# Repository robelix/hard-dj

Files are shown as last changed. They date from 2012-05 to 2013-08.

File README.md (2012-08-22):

# HardDJ - Arduino Mega based DJ MIDI Controller

using old Harddisks as jog wheels

Have a look to the wiki https://github.com/robelix/hard-dj/wiki for more documentation  

## Contents:

* arduino/libraries - Required arduino libs
* arduino/sketchbook - arduino code
* encoder - encoder wheels for lasercutting
* mixxx - MIDI-mapping for mixxx http://mixxx.org/
* eagle - sketches and pcbs
* ttymidi - serial to midi tool for linux

## License:
CC-BY-SA Roland "robelix" Obermayer <roland at robelix.com>
http://creativecommons.org/licenses/by-sa/3.0/at/

## Tools and libs with diffrent licenses

### Encoder wheel generator script
encoder/make_encoder.perl  
http://thedenneys.org/pub/robot/encoders/  
by Bryce Denney <bryce at tlw.com>  
License: GPL 2 or later  

### Arduino MIDI lib
arduino/libraries/MIDI/  
http://arduino.cc/playground/Main/MIDILibrary  
by Francois Best  
License: GPL  

### Arduino Encoder lib
arduino/libraries/Encoder/  
http://www.pjrc.com/teensy/td_libs_Encoder.html  
by PJRC.COM, LLC - Paul Stoffregen <paul@pjrc.com>  
License: MIT  

### ttymidi
ttymidi/  
http://www.varal.org/ttymidi/  
by Thiago Teixeira, Jari Suominen  
License GPL 3 or later

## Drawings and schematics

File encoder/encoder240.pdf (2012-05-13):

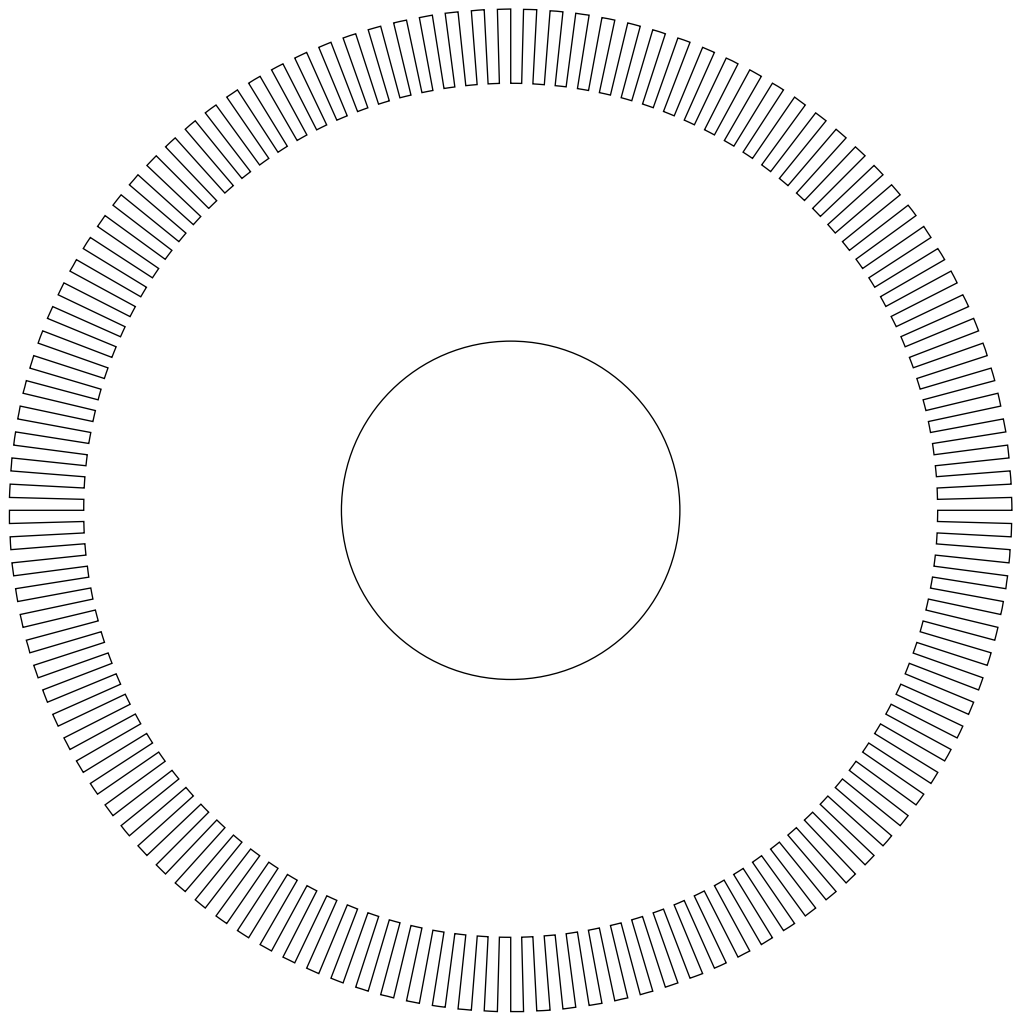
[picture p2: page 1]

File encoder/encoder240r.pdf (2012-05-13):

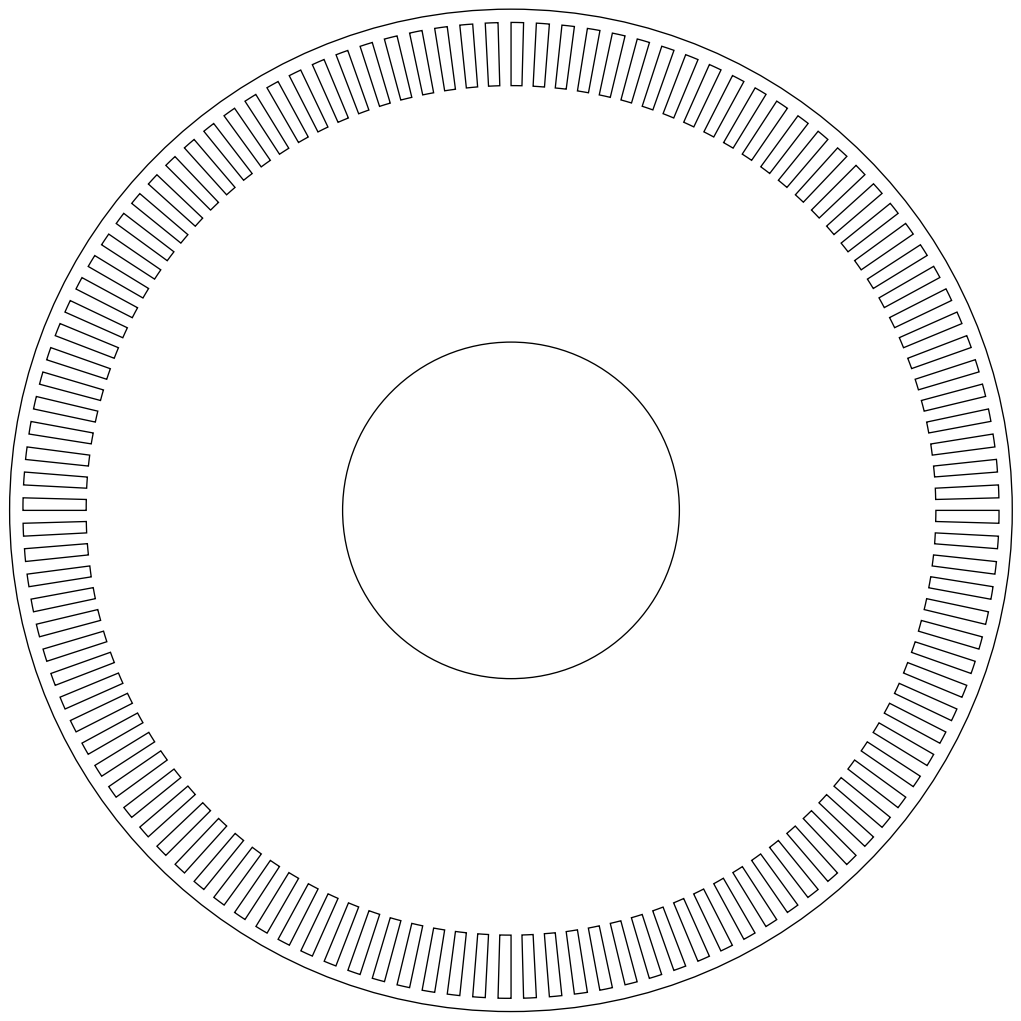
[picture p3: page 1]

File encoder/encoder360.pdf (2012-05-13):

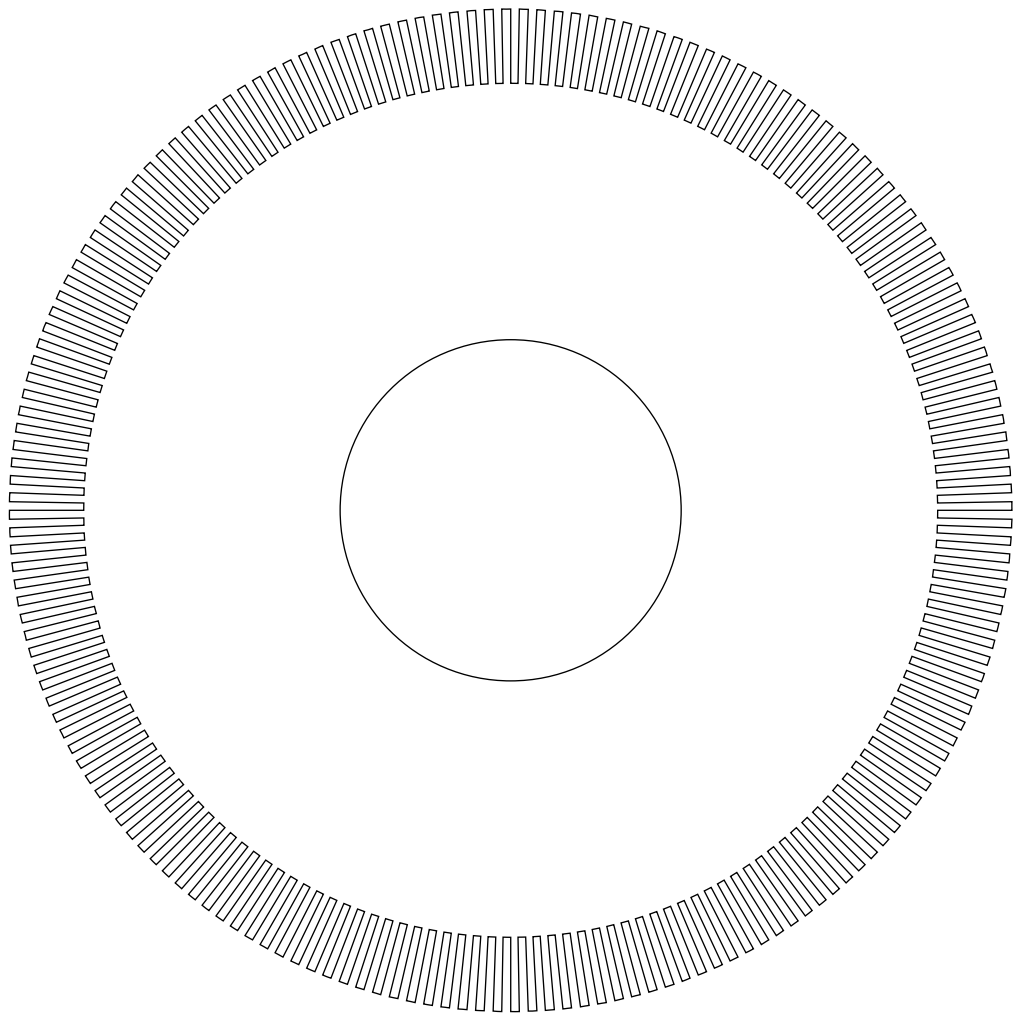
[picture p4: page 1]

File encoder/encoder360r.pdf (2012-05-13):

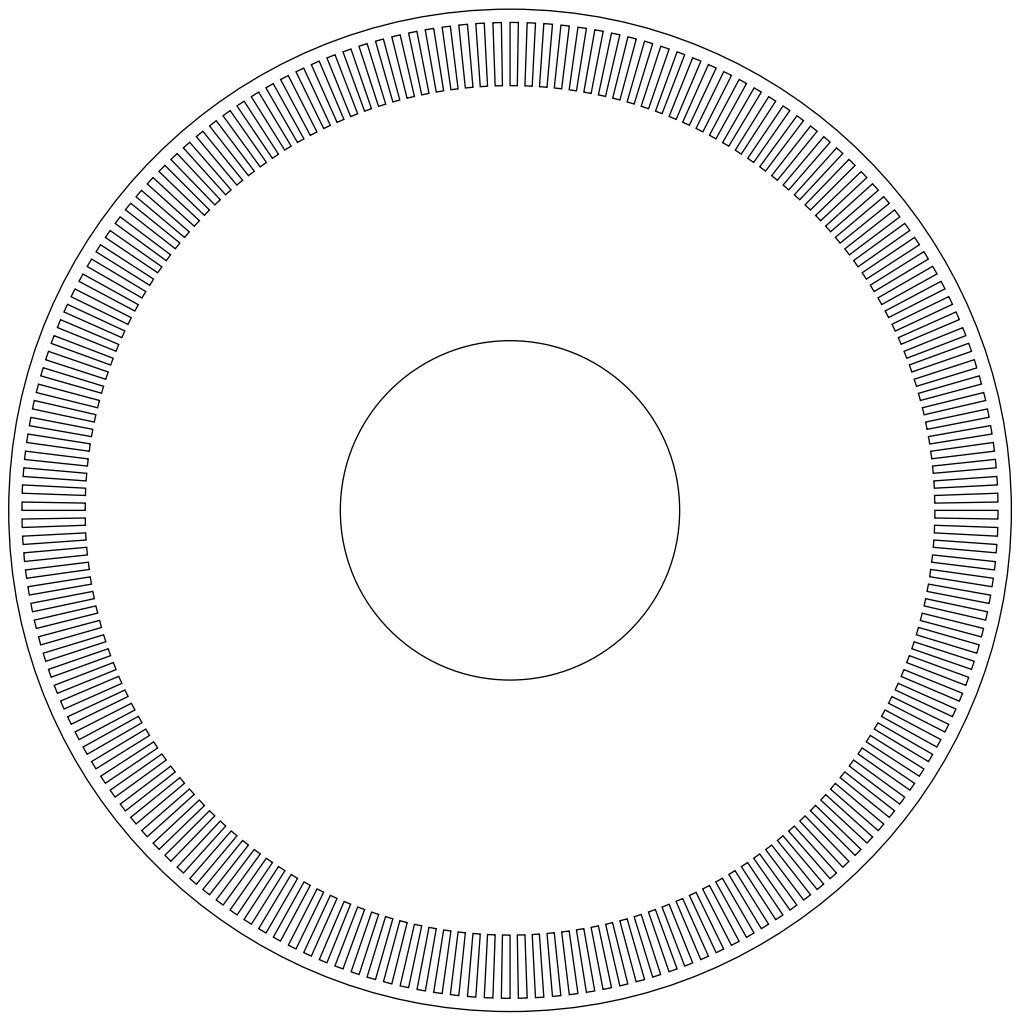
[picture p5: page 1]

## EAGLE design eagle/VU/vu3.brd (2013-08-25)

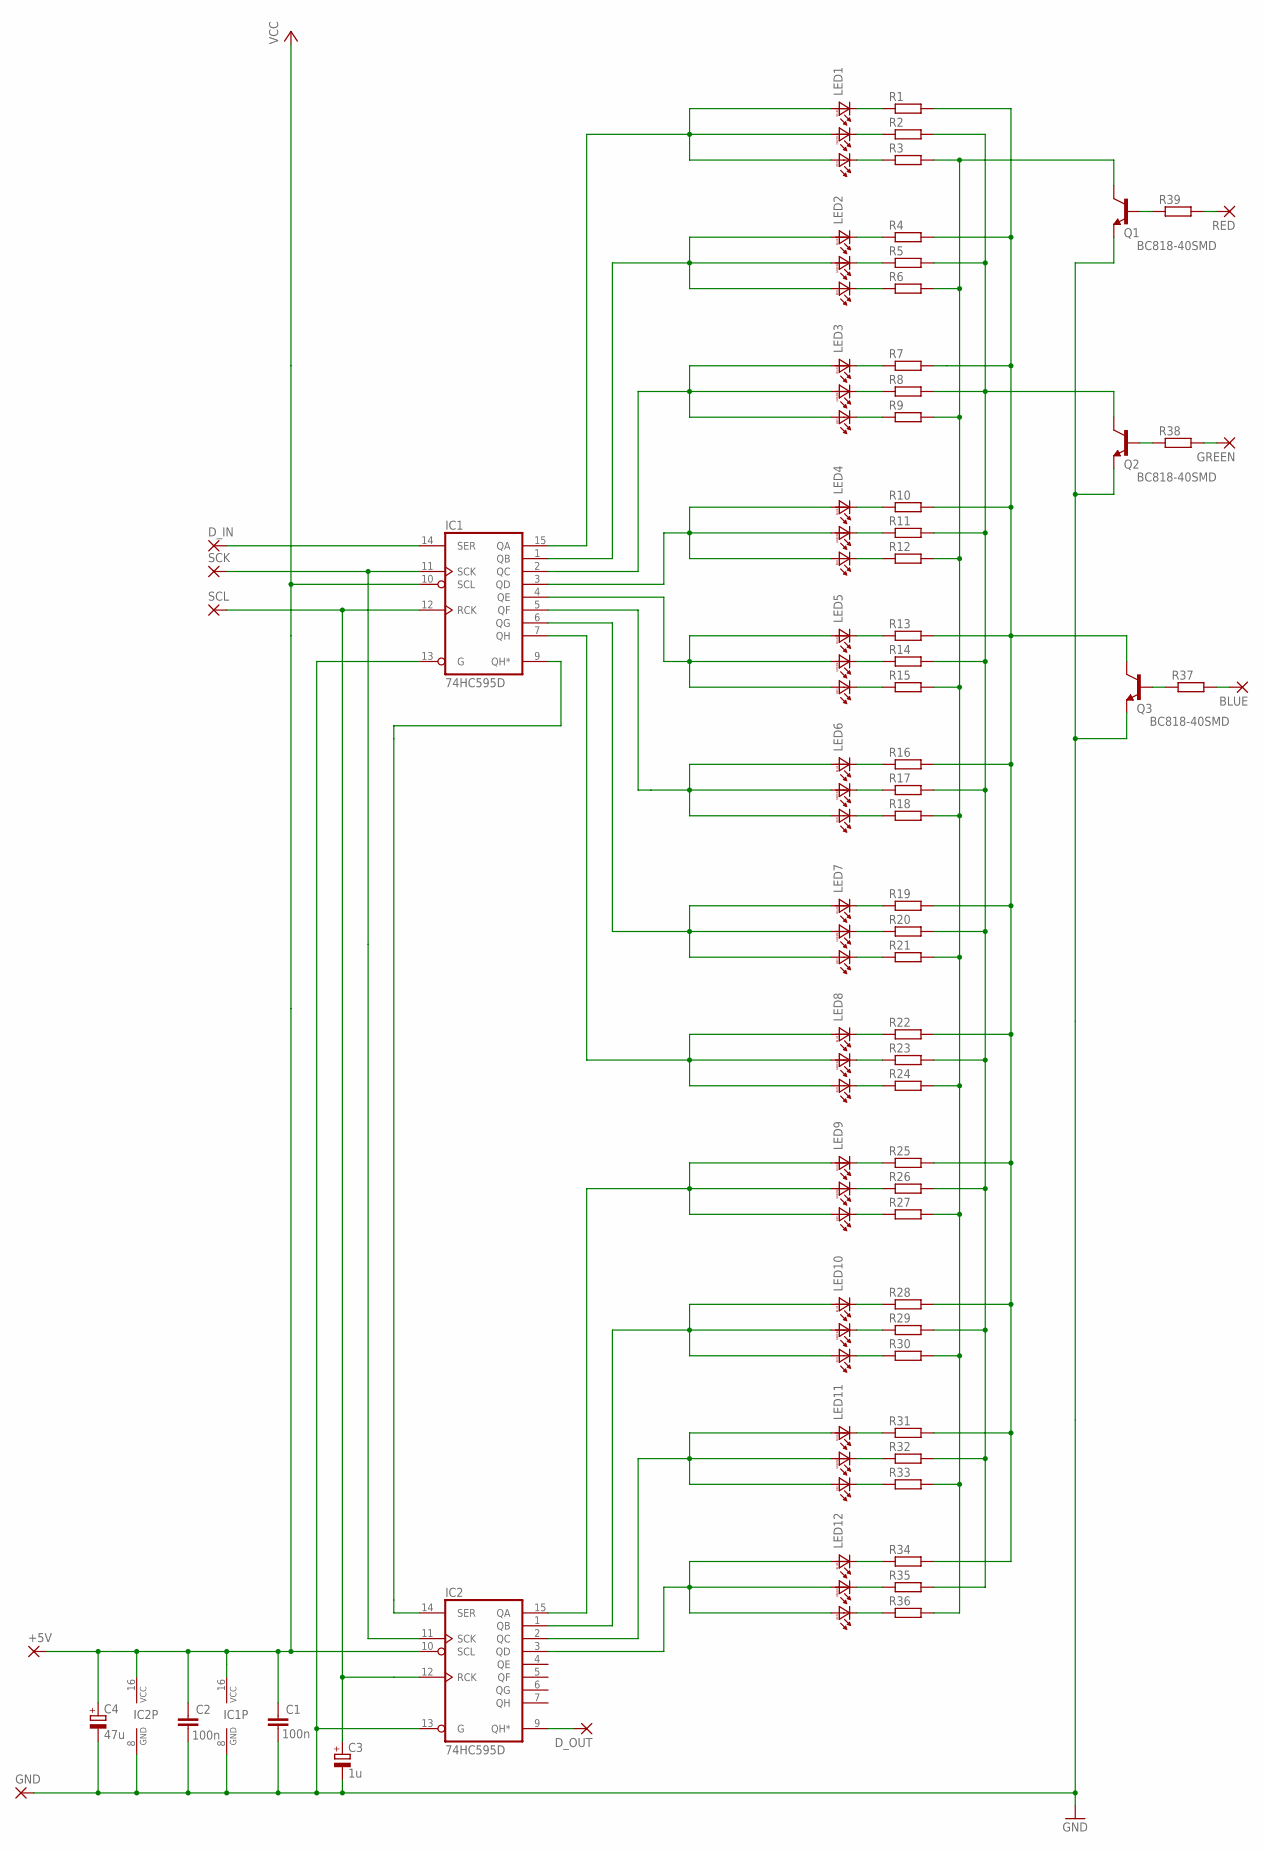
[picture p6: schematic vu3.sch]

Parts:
+5V: 2,54/0,8
BLUE: 2,54/0,8
C1, C2: 100n; C1206
C3: 1u; E5-5-L-12SMD
C4: 47u; E2,5-5-L-12SMD
D_IN: 2,54/0,8
D_OUT: 2,54/0,8
GND: 2,54/0,8
GREEN: 2,54/0,8
IC1, IC2: 74HC595D; SO16
LED1, LED2, LED3, LED4, LED5, LED6, LED7, LED8, LED9, LED10, LED11, LED12: LED_RGB_PLCC6; PLCC6
Q1, Q2, Q3: BC818-40SMD; SOT23-BEC
R1, R2, R3, R4, R5, R6, R7, R8, R9, R10, R11, R12, R13, R14, R15, R16, R17, R18, R19, R20, R21, R22, R23, R24, R25, R26, R27, R28, R29, R30, R31, R32, R33, R34, R35, R36, R37, R38, R39: R-EU_R1206; R1206
RED: 2,54/0,8
SCK: 2,54/0,8
SCL: 2,54/0,8

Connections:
unnamed: LED1.BC, R1.1
unnamed: R39.2, RED.1
unnamed: LED1.RC, R3.1
unnamed: LED2.GC, R5.1
unnamed: IC1.11 (SCK), IC2.11 (SCK), SCK.1
unnamed: LED3.BC, R7.1
unnamed: LED3.RC, R9.1
unnamed: +5V.1, C1.1, C2.1, C4.+, IC1.10 (SCL), IC1.16 (VCC), IC2.10 (SCL), IC2.16 (VCC)
unnamed: LED4.GC, R11.1
unnamed: IC2.15 (QA), LED9.BA, LED9.GA, LED9.RA
unnamed: LED5.BC, R13.1
unnamed: LED1.GC, R2.1
unnamed: LED5.RC, R15.1
unnamed: LED2.BC, R4.1
unnamed: LED6.GC, R17.1
unnamed: LED2.RC, R6.1
unnamed: LED7.BC, R19.1
unnamed: LED3.GC, R8.1
unnamed: LED7.RC, R21.1
unnamed: LED4.BC, R10.1
unnamed: LED8.GC, R23.1
unnamed: LED4.RC, R12.1
unnamed: LED9.BC, R25.1
unnamed: LED5.GC, R14.1
unnamed: LED9.RC, R27.1
unnamed: LED6.BC, R16.1
unnamed: LED10.GC, R29.1
unnamed: LED6.RC, R18.1
unnamed: LED11.BC, R31.1
unnamed: LED7.GC, R20.1
unnamed: LED11.RC, R33.1
unnamed: LED8.BC, R22.1
unnamed: LED12.GC, R35.1
unnamed: LED8.RC, R24.1
unnamed: LED9.GC, R26.1
unnamed: LED10.BC, R28.1
unnamed: LED10.RC, R30.1
unnamed: LED11.GC, R32.1
unnamed: LED12.BC, R34.1
unnamed: LED12.RC, R36.1
unnamed: GREEN.1, R38.2
unnamed: IC1.9 (QH*), IC2.14 (SER)
unnamed: Q3.B, R37.1
unnamed: BLUE.1, R37.2
unnamed: Q2.B, R38.1
unnamed: IC1.1 (QB), LED2.BA, LED2.GA, LED2.RA
unnamed: IC1.2 (QC), LED3.BA, LED3.GA, LED3.RA
unnamed: IC1.3 (QD), LED4.BA, LED4.GA, LED4.RA
unnamed: IC1.4 (QE), LED5.BA, LED5.GA, LED5.RA
unnamed: IC1.5 (QF), LED6.BA, LED6.GA, LED6.RA
unnamed: IC1.6 (QG), LED7.BA, LED7.GA, LED7.RA
unnamed: C1.2, C2.2, C3.-, C4.-, GND.1, IC1.8 (GND), IC1.13 (G), IC2.8 (GND), IC2.13 (G), Q1.E, Q2.E, Q3.E
unnamed: D_IN.1, IC1.14 (SER)
unnamed: IC1.7 (QH), LED8.BA, LED8.GA, LED8.RA
unnamed: Q1.B, R39.1
unnamed: Q3.C, R1.2, R4.2, R7.2, R10.2, R13.2, R16.2, R19.2, R22.2, R25.2, R28.2, R31.2, R34.2
unnamed: IC1.15 (QA), LED1.BA, LED1.GA, LED1.RA
unnamed: Q2.C, R2.2, R5.2, R8.2, R11.2, R14.2, R17.2, R20.2, R23.2, R26.2, R29.2, R32.2, R35.2
unnamed: C3.+, IC1.12 (RCK), IC2.12 (RCK), SCL.1
unnamed: D_OUT.1, IC2.9 (QH*)
unnamed: Q1.C, R3.2, R6.2, R9.2, R12.2, R15.2, R18.2, R21.2, R24.2, R27.2, R30.2, R33.2, R36.2
unnamed: IC2.1 (QB), LED10.BA, LED10.GA, LED10.RA
unnamed: IC2.2 (QC), LED11.BA, LED11.GA, LED11.RA
unnamed: IC2.3 (QD), LED12.BA, LED12.GA, LED12.RA

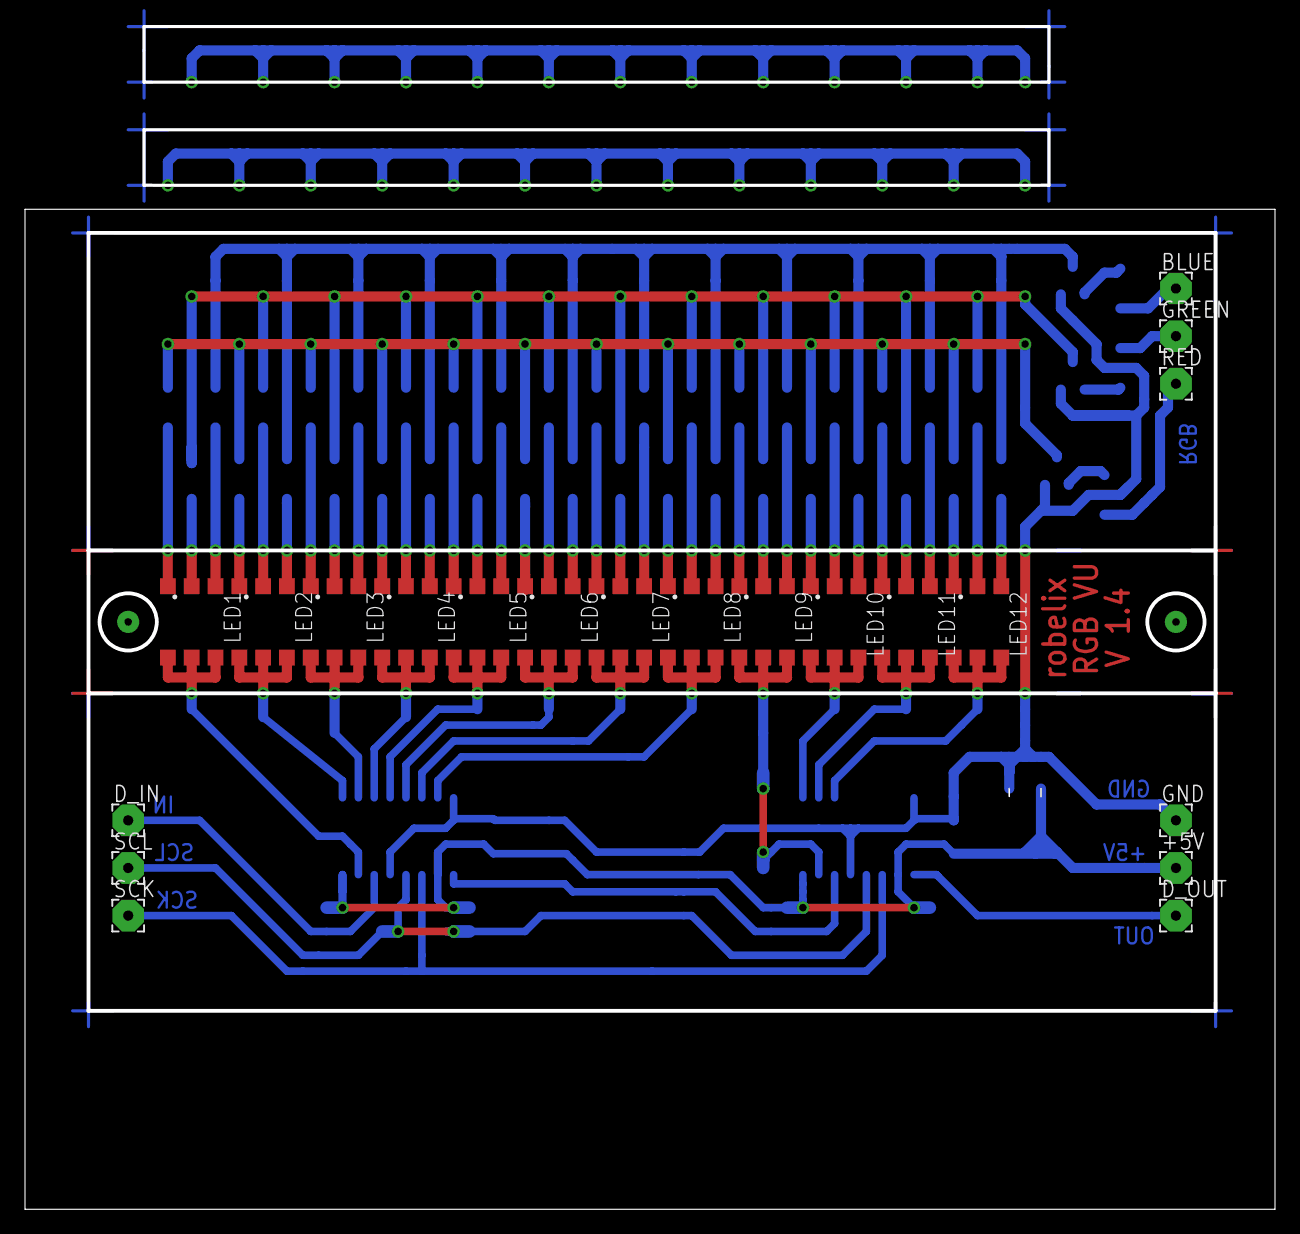
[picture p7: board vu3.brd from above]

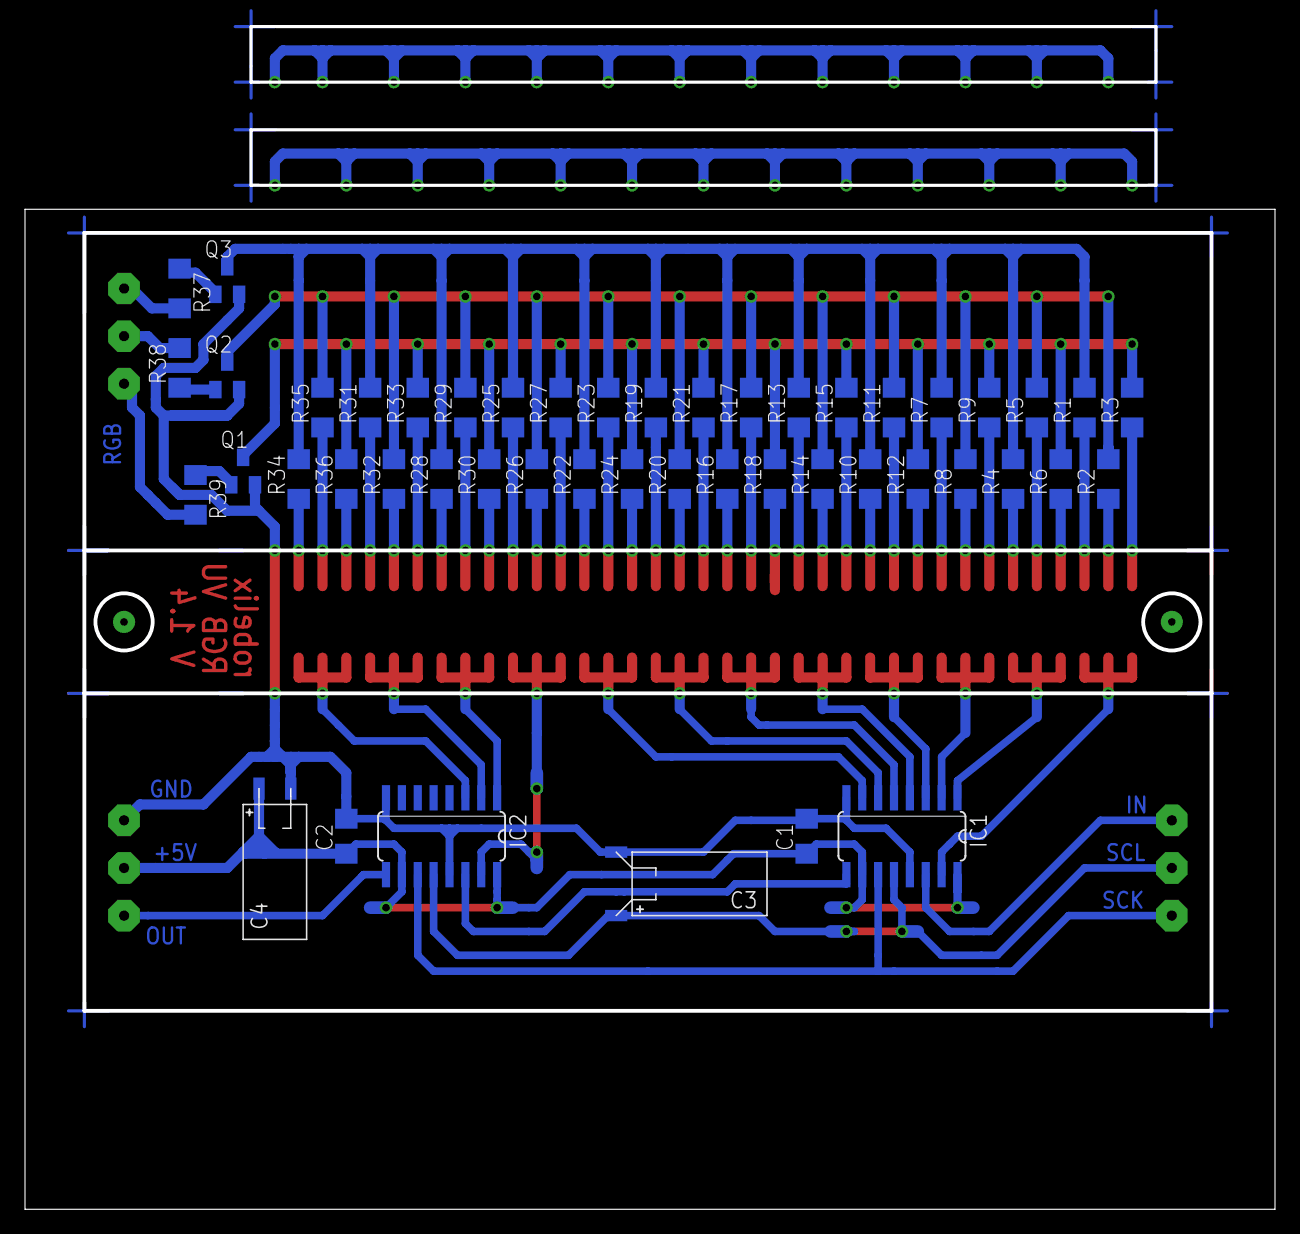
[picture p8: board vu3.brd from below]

Board: 2 copper layers, 100.0 x 80.0 mm, 69 parts (48 on the bottom side), 64 nets.

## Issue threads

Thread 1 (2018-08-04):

led connection hard-dj

digitekelettronica, 2018-08-04:
excuse me, the pins of the 74hc595, on which pin atmega connect

robelix, 2018-08-27:
Hi!
Make sure that mixxx sends out midi - if you are using linux+ttymidi run: ttymidi -v -s /dev/ttyxxx

digitekelettronica, 2018-08-27:
Ok,thanks,another problem on encoder,the comunication with pc is ok,data
midi trasmitteing,mixxx not read data encoder to script.
Tested mixxx 1.11 and midi receiver,with mixxx 2.0 and 2.1 midi signal not
receiver.
This project is fantastic.
Thanks

Il lun 27 ago 2018, 11:48 robelix <notifications@github.com> ha scritto:

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

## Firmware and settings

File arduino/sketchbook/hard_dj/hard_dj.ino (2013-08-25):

/*
 HD Dj-Control
 
 created 2012
 by robelix <roland@robelix.com>
 
 Licence: Creative Commons CC-BY-SA 3.0
 
 for Arduino Mega 2560
 
*/


// Libs //

#define ENCODER_OPTIMIZE_INTERRUPTS
#include <Encoder.h>
#include <MIDI.h>



// MIDI //

#define MIDI_LISTEN_CHANNEL  4
#define MIDI_BUTTON_CHANNEL  1
#define MIDI_FADER_CHANNEL   2
#define MIDI_ENCODER_CHANNEL 3

#define NOTE_VU_DECK_LEFT   119
#define NOTE_VU_DECK_RIGHT  120
#define NOTE_VU_MASTER_L    121
#define NOTE_VU_MASTER_R    122
#define NOTE_CASE_LEDS      123



// BUTTONS //

#define KEYMATRIX_ROWS 10
#define KEYMATRIX_COLS 4
#define KEYMATRIX_DEBOUNCE 4

byte keymatrixRowPins[KEYMATRIX_ROWS] = {22, 24, 26, 28, 30, 32, 34, 31, 33, 35};
byte keymatrixColPins[KEYMATRIX_COLS] = {23, 25, 27, 29};

boolean keymatrixStates[KEYMATRIX_ROWS][KEYMATRIX_COLS];
unsigned long keymatrixDebounce[KEYMATRIX_ROWS][KEYMATRIX_COLS];



// LEDS //

//Pin connected to latch pin (ST_CP) of 74HC595
#define LEDS_LATCH_PIN 51
//Pin connected to clock pin (SH_CP) of 74HC595
#define LEDS_CLOCK_PIN 52
////Pin connected to Data in (DS) of 74HC595
#define LEDS_DATA_PIN 53
// nr of shift registers
#define LEDS_NR_OF_74HC595 5

byte ledsData[LEDS_NR_OF_74HC595];
boolean ledsDataChanged = false;

#define PIN_PWM_CASE_LEDS 13



// VU //

// VU Numbers
#define VU_MASTER_LEFT 0
#define VU_MASTER_RIGHT 1
#define VU_DECK_LEFT 2
#define VU_DECK_RIGHT 3

//Pins connected to latch pin (ST_CP) of 74HC595
const int VU_LATCH_PINS[4] = {49,43,39,38};
//Pins connected to clock pin (SH_CP) of 74HC595
const int VU_CLOCK_PINS[4] = {50,47,41,40};
////Pins connected to Data in (DS) of 74HC595
const int VU_DATA_PINS[4]  = {48,42,37,36};

// VU RGB Pins
const int VU_PWM_PINS_R[4] = {45,8,2,5};
const int VU_PWM_PINS_G[4] = {44,9,3,6};
const int VU_PWM_PINS_B[4] = {46,10,4,7};

// VU Mode
int vuMode[4] = {0,0,0,0};

// VU Data
byte vuData[4][2] = { {0,0}, {0,0}, {0,0}, {0,0} };

// RGB Colors for Master VU dependent on value
int masterColors[12][3] = {
  {0,0,255}, 
  {0,55,200},
  {0,100,155},
  {0,200,55},
  {0,255,0},
  {0,255,0},
  {0,255,0},
  {0,255,0},
  {50,200,0},
  {100,155,0},
  {200,55,0},
  {255,0,0}
};


// FADER & POTIS //

#define NR_OF_FADERS 11
const int pinFader[NR_OF_FADERS] = { A0,A1,A2,A3,A4,A5,A6,A7,A8,A9,A10 };
int faderState[NR_OF_FADERS] = {0,0,0,0,0,0,0,0,0,0,0};
#define FADER_CHANGE_MIN 8

// Fader Numbers
#define FADER_CROSSFADER 10
#define FADER_MASTER_LEFT 8
#define FADER_GAIN_LEFT 3
#define FADER_HIGH_LEFT 2
#define FADER_MID_LEFT 1
#define FADER_BASS_LEFT 0
#define FADER_MASTER_RIGHT 9
#define FADER_GAIN_RIGHT 7
#define FADER_HIGH_RIGHT 6
#define FADER_MID_RIGHT 5
#define FADER_BASS_RIGHT 4



// ENCODER //

#define ENCODER_L_PIN_A 18
#define ENCODER_L_PIN_B 16

#define ENCODER_R_PIN_A 19
#define ENCODER_R_PIN_B 17

volatile byte encoderLPos = 0;
volatile byte encoderRPos = 0;

volatile unsigned long encoderLtstamp = 0;
volatile unsigned long encoderRtstamp = 0;

Encoder leftEncoder(ENCODER_L_PIN_A, ENCODER_L_PIN_B);
Encoder rightEncoder(ENCODER_R_PIN_A, ENCODER_R_PIN_B);



void setup() {

  // MIDI Setup
  MIDI.begin(MIDI_LISTEN_CHANNEL);
  Serial.begin(115200);
  MIDI.setHandleNoteOn(handleNoteOn);
  MIDI.setHandleNoteOff(handleNoteOff);

  // LEDs    
  pinMode(LEDS_LATCH_PIN, OUTPUT);
  pinMode(LEDS_CLOCK_PIN, OUTPUT);  
  pinMode(LEDS_DATA_PIN,  OUTPUT);
  for (int i=0; i < LEDS_NR_OF_74HC595; i++) {
    ledsData[i] = 0;
  }
  pinMode(PIN_PWM_CASE_LEDS, OUTPUT);
  
  // init vu
  for (int i=0; i<4; i++) {
    pinMode(VU_LATCH_PINS[i], OUTPUT);
    pinMode(VU_DATA_PINS[i],  OUTPUT);  
    pinMode(VU_CLOCK_PINS[i], OUTPUT);
    pinMode(VU_PWM_PINS_R[i], OUTPUT);
    pinMode(VU_PWM_PINS_G[i], OUTPUT);
    pinMode(VU_PWM_PINS_B[i], OUTPUT);
    
    // testing vu - all to halft bright
    analogWrite(VU_PWM_PINS_R[i], 127);
    analogWrite(VU_PWM_PINS_G[i], 127);
    analogWrite(VU_PWM_PINS_B[i], 127);
    
    setVU(0,i);
  }

  // keymatrix
  initKeymatrix();
};



void loop(){
  checkEncoders();
  readKeymatrix();
  checkFaders();
  MIDI.read();
  shiftOutLEDS();
};



void handleNoteOn(byte channel, byte note, byte velocity) {
    if (note/8 < LEDS_NR_OF_74HC595 ) {
      writeLED(note,HIGH);
    }
    else if(note == NOTE_VU_DECK_LEFT) {
      setVU(velocity, VU_DECK_LEFT);
    }
    else if(note == NOTE_VU_DECK_RIGHT) {
      setVU(velocity, VU_DECK_RIGHT);
    }
    else if(note == NOTE_VU_MASTER_L) {
      setVU(velocity, VU_MASTER_LEFT);
    }
    else if(note == NOTE_VU_MASTER_R) {
      setVU(velocity, VU_MASTER_RIGHT);
    }
    else if(note == NOTE_CASE_LEDS) {
      setCaseLeds(velocity);
    }
}


void handleNoteOff(byte channel, byte note, byte velocity) {
    if (note/8 < LEDS_NR_OF_74HC595 ) {
      writeLED(note,LOW);
    }
}


void setCaseLeds(byte value) {
  analogWrite(PIN_PWM_CASE_LEDS, value*2);
}


void writeLED(byte ledNr, byte highlow) {
  byte chipNr = ledNr/8;
  byte pinNr = ledNr%8;
  if(chipNr < LEDS_NR_OF_74HC595) {
    bitWrite(ledsData[chipNr], pinNr, highlow);
    ledsDataChanged = true;
  }
}


void shiftOutLEDS() {
  if (ledsDataChanged) {
    digitalWrite(LEDS_LATCH_PIN, LOW);
    // shift out in reverse order
    for(int i = LEDS_NR_OF_74HC595-1; i>=0; i--) {
      shiftOut(LEDS_DATA_PIN, LEDS_CLOCK_PIN, MSBFIRST, ledsData[i]);
    }
  }
  digitalWrite(LEDS_LATCH_PIN, HIGH);
  ledsDataChanged = false;
}



void checkEncoders() {
  byte newPos = leftEncoder.read();
  if (newPos != encoderLPos) {
    MIDI.sendControlChange(1, byte( newPos % 128 ), MIDI_ENCODER_CHANNEL); 
    encoderLPos = newPos;
  }
  newPos = rightEncoder.read();
  if (newPos != encoderRPos) {
    MIDI.sendControlChange(2, byte(newPos % 128 ), MIDI_ENCODER_CHANNEL);
    encoderRPos = newPos;
  }
}



void checkFaders() {
  for( int i=0; i<NR_OF_FADERS; i++ ) {
    checkFader(i);
  }
}



void initKeymatrix() {
  
  // clear arrays
  for (byte r=0; r<KEYMATRIX_ROWS; r++) {
    for (byte c=0; c<KEYMATRIX_COLS; c++) {
      keymatrixStates[r][c]=0;
      keymatrixDebounce[r][c]=0;
    }
  }
  
  //configure column pin modes and states
  for (byte c=0; c<KEYMATRIX_COLS; c++) {
      pinMode(keymatrixColPins[c],OUTPUT);
      digitalWrite(keymatrixColPins[c],LOW);
  }
  
  //configure row pin modes and states
  for (byte r=0; r<KEYMATRIX_ROWS; r++) {
      pinMode(keymatrixRowPins[r],INPUT);
      digitalWrite(keymatrixRowPins[r],HIGH);	// Enable the internal 20K pullup resistors for each row pin.
  }
  
}


void readKeymatrix() {
  
  // run through cols
  for( int c=0; c<KEYMATRIX_COLS; c++) {
    digitalWrite(keymatrixColPins[c], LOW);
    
    // check rows
    for( int r=0; r<KEYMATRIX_ROWS; r++) {
      boolean currentValue = (digitalRead(keymatrixRowPins[r])<1);
      if (currentValue != keymatrixStates[r][c]) {

        // debounce
        unsigned long currentTime = millis();
        if(currentTime-KEYMATRIX_DEBOUNCE > keymatrixDebounce[r][c]) {
          
          int keyNr = r*KEYMATRIX_COLS+c;
          sendKeyMessage(keyNr, currentValue);
          keymatrixStates[r][c] = currentValue;
          keymatrixDebounce[r][c] = currentTime;
        }
      }
    }

    // reset col
    digitalWrite(keymatrixColPins[c], HIGH);
  }

};


void sendKeyMessage(int keyNr, boolean value) {
  if (value) {
    MIDI.sendNoteOn(byte(keyNr), 1, MIDI_BUTTON_CHANNEL);
  } else {
    MIDI.sendNoteOff(byte(keyNr), 1, MIDI_BUTTON_CHANNEL);
  }
}



void checkFader(int i) {
  int fdrValue = analogRead(pinFader[i]);
  if( fdrValue != faderState[i] ) {
    if( abs(fdrValue - faderState[i]) > FADER_CHANGE_MIN) {
      MIDI.sendControlChange(byte(i), byte(fdrValue/8), MIDI_FADER_CHANNEL); // value bis 127
      faderState[i] = fdrValue;

      // VU color changes
      switch (i) {
        case FADER_BASS_LEFT:
          setVuR( byte(fdrValue/4), VU_DECK_LEFT);
        break;
        
        case FADER_MID_LEFT:
          setVuG( byte(fdrValue/4), VU_DECK_LEFT);
        break;
        
        case FADER_HIGH_LEFT:
          setVuB( byte(fdrValue/4), VU_DECK_LEFT);
        break;
        
        case FADER_BASS_RIGHT:
          setVuR( byte(fdrValue/4), VU_DECK_RIGHT);
        break;
        
        case FADER_MID_RIGHT:
          setVuG( byte(fdrValue/4), VU_DECK_RIGHT);
        break;
        
        case FADER_HIGH_RIGHT:
          setVuB( byte(fdrValue/4), VU_DECK_RIGHT);
        break;
      }
    }
  }
}
    




// set vu meter
void setVU(int value, int vuNr) {
  value = value-1;
  for (int i=0; i < 12; i++) {
    if (i<= value) {
      writeVuLED(i, HIGH, vuNr);
    } else {
      writeVuLED(i, LOW, vuNr);
    }
  }
  shiftOutVu(vuNr);
  if (vuNr == VU_MASTER_LEFT || vuNr == VU_MASTER_RIGHT) {
    setVuRGBbyValue(value, vuNr);
  } 
}

void setVuRGBbyValue(int value, int vuNr) {
  int r = masterColors[value][0];
  int g = masterColors[value][1];
  int b = masterColors[value][2];
  setVuRGB(r,g,b,vuNr);
}

void setVuRGB(int r, int g, int b, int vuNr) {
    analogWrite(VU_PWM_PINS_R[vuNr], r);
    analogWrite(VU_PWM_PINS_G[vuNr], g);
    analogWrite(VU_PWM_PINS_B[vuNr], b);
}

void setVuR(int r, int vuNr) {
  analogWrite(VU_PWM_PINS_R[vuNr], r);
}
void setVuG(int g, int vuNr) {
  analogWrite(VU_PWM_PINS_G[vuNr], g);
}
void setVuB(int b, int vuNr) {
  analogWrite(VU_PWM_PINS_B[vuNr], b);
}

void writeVuLED(byte ledNr, byte highlow, int vuNr) {
  // they are built in in reverse order
  ledNr = 15 - ledNr -4;
  
  byte chipNr = ledNr / 8;
  byte pinNr = ledNr % 8;
  if(chipNr < 2) {
    bitWrite(vuData[vuNr][chipNr], pinNr, highlow);
  }
}

void shiftOutVu(int vuNr) {
  digitalWrite(VU_LATCH_PINS[vuNr], LOW);
  // shift out in reverse order
  for(int i = 1; i>=0; i--) {
    shiftOut(VU_DATA_PINS[vuNr], VU_CLOCK_PINS[vuNr], MSBFIRST, vuData[vuNr][i]);
  }
  digitalWrite(VU_LATCH_PINS[vuNr], HIGH);
}

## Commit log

2012-05-13 Enocder-script & Encoder Files added
2012-05-17 first controller software - faders, potis, encoders, buttons
2012-05-17 eagle sketches of encoder & potis
    [hard-dj.sch]
2012-05-17 renamed to arduino-compativle
2012-05-17 Encoder library from http://www.pjrc.com/teensy/td_libs_Encoder.html added
2012-05-17 using optimized encoder
2012-05-18 arduino midi lib 3.2 added
2012-05-18 first success with midi-sending - play leds
2012-07-09 shift registers for leds
2012-07-09 mixxx-mappings for small keypads and some leds
2012-07-15 case leds added
2012-08-06 filename and include changed to work with arduino 1.0.x
2012-08-06 Corrected Pin numbers in sketches
    [hard-dj.sch]
2012-08-06 keymatrix sketch
    [keymatrix.sch]
2012-08-22 device strings changed in ttymidi - if they are not the same for in and out mixxx thinks these are diffrent devices
2012-08-30 additional buttons and leds
2012-08-31 mixxx midi bindings for the added buttons and some cleanup of duplicate functions
2013-08-25 RGB-VUs added
    [vu3.brd, vu3.sch]
